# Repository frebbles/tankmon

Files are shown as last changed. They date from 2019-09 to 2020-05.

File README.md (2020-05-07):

# TankMon

A no frills dual tank water level monitoring solution incorporating:

- ESP8266 low power ultrasonic measurer remote monitor and reporter device for dual tank setups [tankmon-probedual] 
Open this in Arduino, ensure that ESP8266 is installed as per the [Adafruit esp8266 arduino guide](https://learn.adafruit.com/adafruit-io-basics-esp8266-arduino/using-arduino-ide)

- PHP server receiver and graph display tool [tankmon]
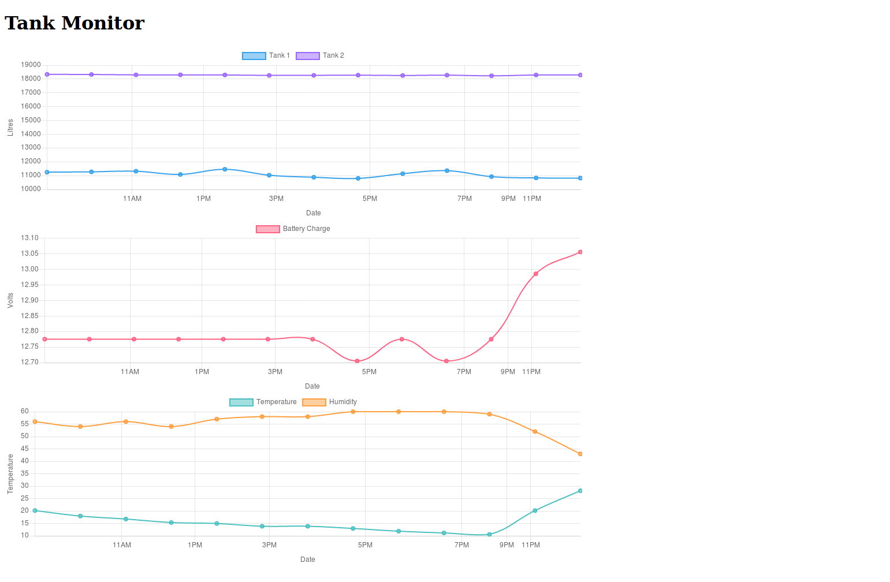
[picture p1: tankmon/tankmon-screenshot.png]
TankMon screenshot


- OpenSCAD construction for Ultrasonic case and ESP8266/NODEMCU case [tankmon-cases]
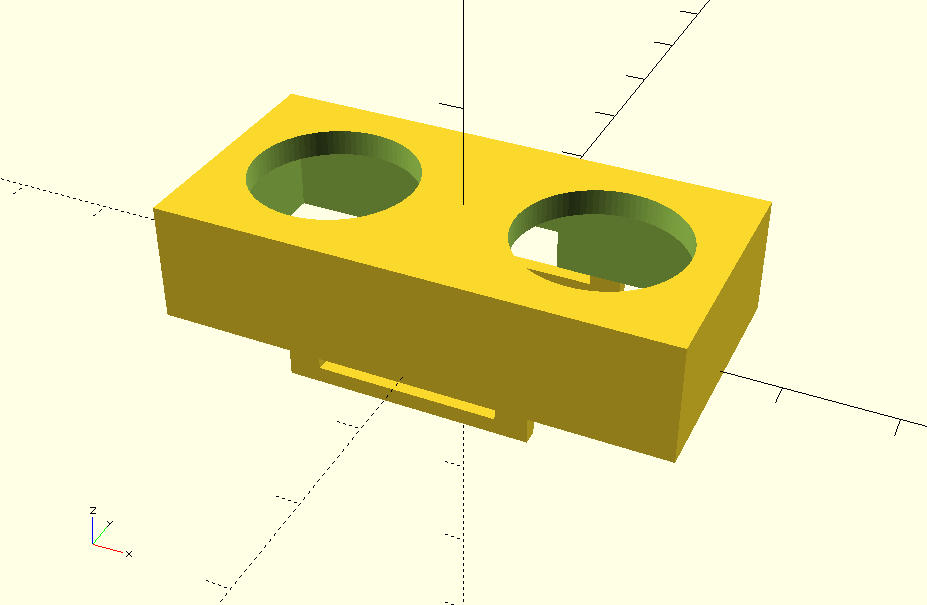
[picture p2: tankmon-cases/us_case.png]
OpenSCAD Ultrasonics case


- Circuit Design and construction for remote monitor circuit and board pcb in KiCAD [tankmon-pcb]
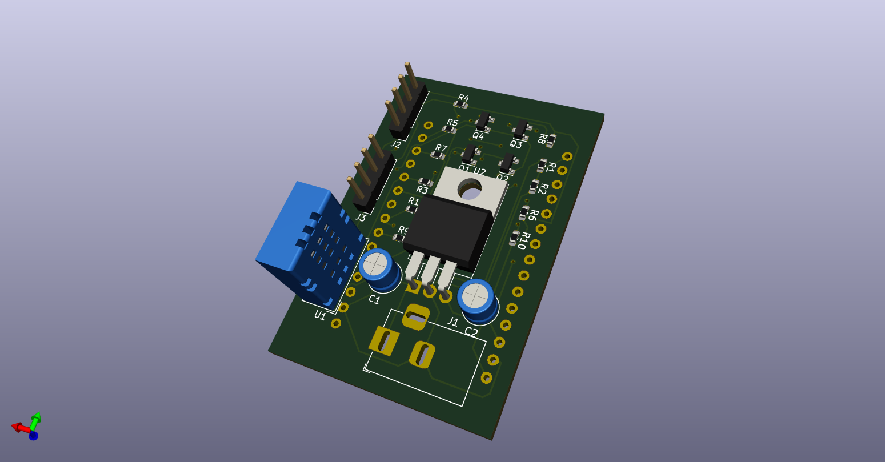
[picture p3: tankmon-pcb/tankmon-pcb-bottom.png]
tankmon-pcb-bottom


A demonstration exercise in, simplifying workflows and modularity, utilising Arduino, NodeMCU, KiCAD, OpenSCAD.

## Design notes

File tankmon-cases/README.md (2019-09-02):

- OpenSCAD case function designs for Make-A-Bracket and Tank fitment for Make-A-Bracket

Function call for make a bracket makes quick development of cases possible, use the following:
use <mab_case_func.scad>

Which simplifies the cases for both the Ultrasonic sensor and the NodeMCU and wiring board.

Work smarter, not harder!

The files us_case and us_case_plug correspond to cases using the above functions for case construction and plug/cap construction.

OpenSCAD Ultrasonics case

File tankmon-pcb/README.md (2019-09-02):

TANKMON NodeMCU PCB adaptor for ultrasonic sensors

These have been designed using KiCAD 5.1.2

Open the project in KiCAD to view/modify the PCB. Export to gerber for sending to your friendly board house for production.

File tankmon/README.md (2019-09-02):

== Tank Monitor Web Scripts

Place these into a /tankmon/ directory of the web server you wish to host this on, the ip/dns of the server must be programmed into the
tankmon-probedual arduino source file for the esp8266 to contact and log the information.

-- Contribs

 - Use of graphing library from ChartJS - minimised and cut down for MVP of graphing required for tank reporting

 - Script for reporting from ESP8266 in remote tank location/s

 - Script for visualisation of past reported tank depth information

 - Tank details stored in CSV file for each individual tank

 - web_test.sh script to start local php service and run browser for testing, (REMOVE before deployment)

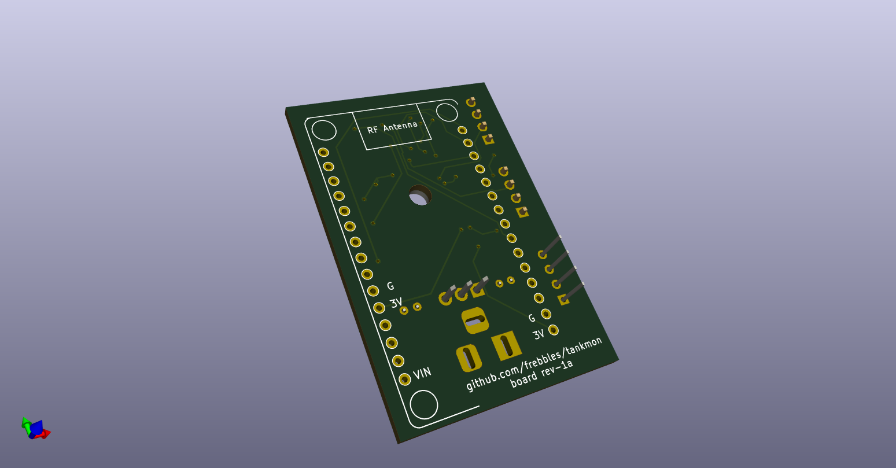
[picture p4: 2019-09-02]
tankmon-pcb/tankmon-pcb-top.png

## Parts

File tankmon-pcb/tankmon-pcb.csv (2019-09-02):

Id | Designator | Package | Quantity | Designation | Supplier and ref
1 | U3 | ESP12F-Devkit-V3-modtext | 1 | NodeMCU_1.0_(ESP-12E)
2 | U2 | TO-220-3_Horizontal_TabDown | 1 | L7805
3 | U1 | Aosong_DHT11_5.5x12.0_P2.54mm | 1 | DHT11
4 | R11,R10,R9,R8,R7,R6,R5,R4 | R_0603_1608Metric | 8 | 10K
5 | R3,R2 | R_0603_1608Metric | 2 | 10k
6 | R1 | R_0603_1608Metric | 1 | 220k
7 | Q4,Q3,Q2,Q1 | SOT-23 | 4 | BSS138
8 | J3,J2 | PinHeader_1x04_P2.54mm_Vertical | 2 | Conn_01x04_Male
9 | J1 | BarrelJack_Horizontal | 1 | Barrel_Jack
10 | C2 | C_Radial_D5.0mm_H5.0mm_P2.00mm | 1 | 0.1uF
11 | C1 | C_Radial_D5.0mm_H5.0mm_P2.00mm | 1 | 0.33uF

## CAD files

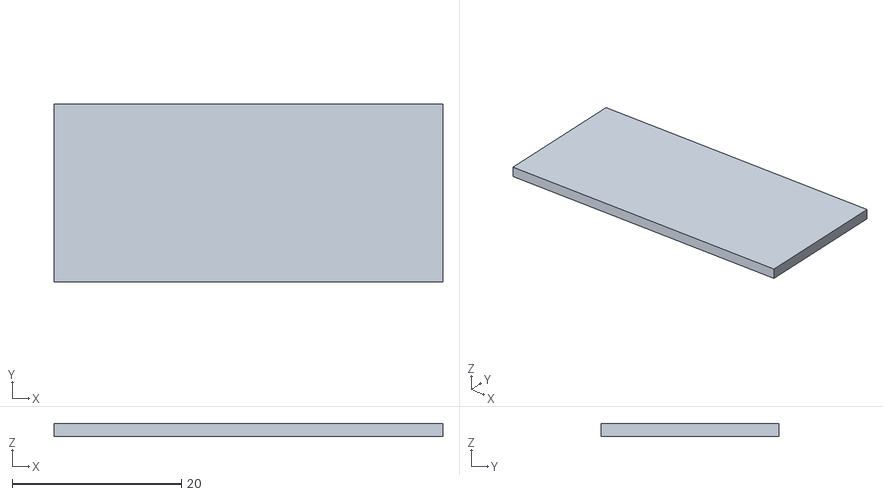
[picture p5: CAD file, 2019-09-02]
tankmon-cases/us_case_plug.stl
46.0 x 21.0 x 1.50

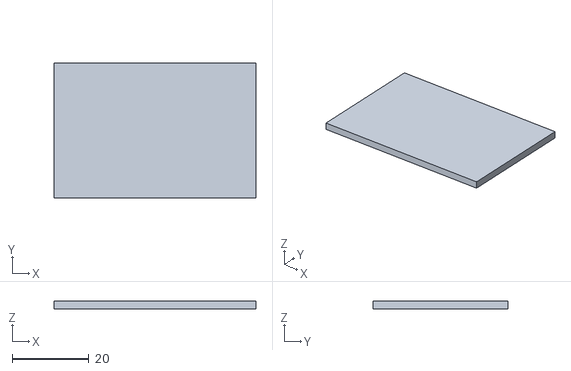
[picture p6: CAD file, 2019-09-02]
tankmon-cases/nodemcu_case_plug_tubemount.stl
52.5 x 35.0 x 2.00

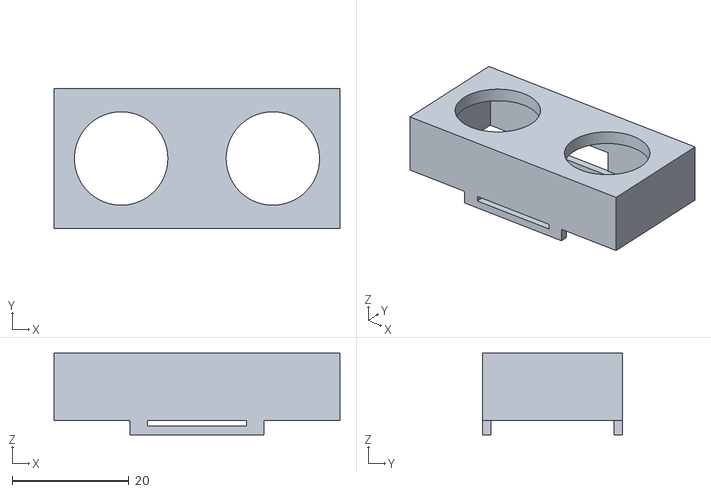
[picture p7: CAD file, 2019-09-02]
tankmon-cases/us_case.stl
49.0 x 24.0 x 14.0

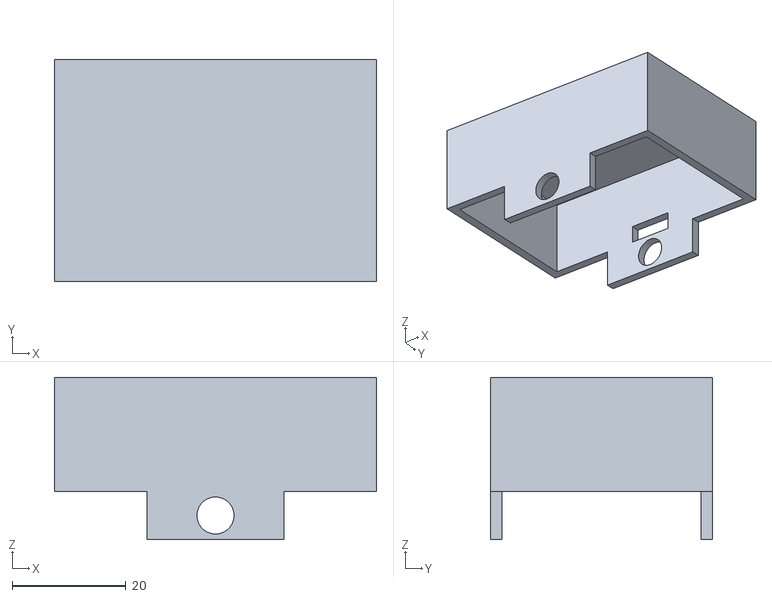
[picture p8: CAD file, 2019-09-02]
tankmon-cases/nodemcu_case_tubemount.stl
56.5 x 39.0 x 28.5

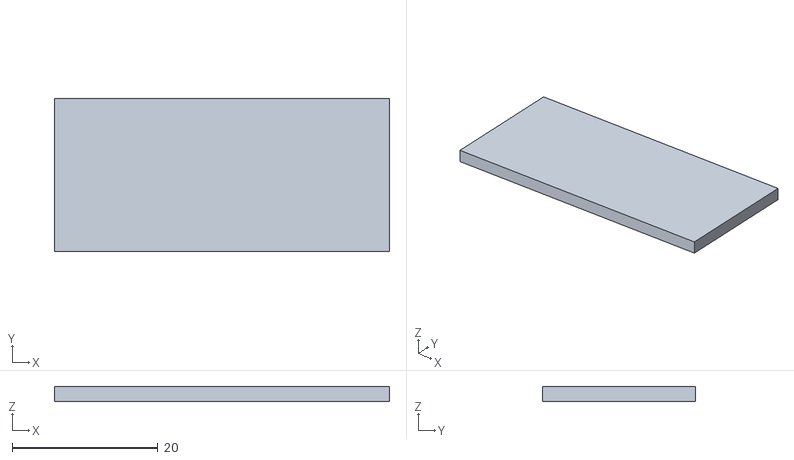
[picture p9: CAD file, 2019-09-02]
tankmon-cases/us_case_plug_tubemount.stl
46.0 x 21.0 x 2.00

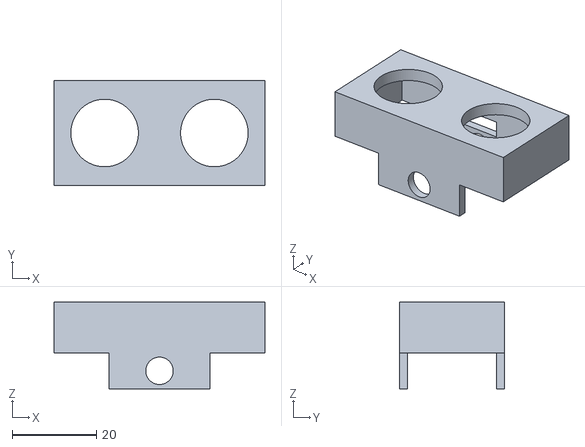
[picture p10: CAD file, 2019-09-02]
tankmon-cases/us_case_tubemount.stl
50.0 x 25.0 x 20.5

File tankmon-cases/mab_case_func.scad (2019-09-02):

echo(version=version());

transblue = [0.5,0.5,0.9,0.8];

mabWidth = 20;
mabThick = 2.5;

// Create case for "Make a bracket" from bunnings warehouse
//mab_rail_case(56, 20, 8.5, 2);
// Create plug for above case
//mab_rail_case_plug(56,20,2);

module mab_rail_case_plug(intwidth, intlength, thickness)
// Subsection plug for case
color("green") 
    translate([0,0,-1])
    linear_extrude(height=thickness)
        square([intwidth,intlength], center= true);


module mab_rail_case(intwidth, intlength, intheight, thickness) {
// Case primary
    
outerlength = intlength + (thickness*2);
outerwidth = intwidth + (thickness*2);
outerheight = intheight + (thickness*2);

union() {

difference() {
union() {
translate([0,(intlength+thickness)/2,-(thickness+1+mabThick)])
linear_extrude(height=thickness + mabThick)
square(size=[(mabWidth + (thickness*2)),thickness], center=true);

translate([0,-(intlength+thickness)/2,-(thickness+1+mabThick)])
linear_extrude(height=thickness + mabThick)
square(size=[(mabWidth + (thickness*2)),thickness], center=true);
}


// For a square sectional mount
translate([0,0,-mabThick-1])
linear_extrude(height=mabThick)
square(size=[mabWidth,intlength*2], center=true);
}


// Main section
difference() {
color(transblue)
    translate([0,0,-1])
        linear_extrude(height=intheight+thickness)
            square([outerwidth, outerlength], center=true);
color("red") 
    translate([0,0,-2])
    linear_extrude(height=intheight)
        square([intwidth,intlength], center= true);
        
color("black")
    translate([0,outerlength/2-thickness/2,-1])
    linear_extrude(height=4)
        square([10,3], center=true);
}
}

}

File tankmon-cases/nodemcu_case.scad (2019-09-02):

use <shaft_mount_func.scad>

cyl_rail_case(52.5,35,18,2);

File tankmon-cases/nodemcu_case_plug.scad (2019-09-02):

use <shaft_mount_func.scad>

cyl_rail_case_plug(52.5,35,2);

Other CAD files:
tankmon-cases/shaft_mount_func.scad
tankmon-cases/us_case.scad
tankmon-cases/us_case_plug.scad

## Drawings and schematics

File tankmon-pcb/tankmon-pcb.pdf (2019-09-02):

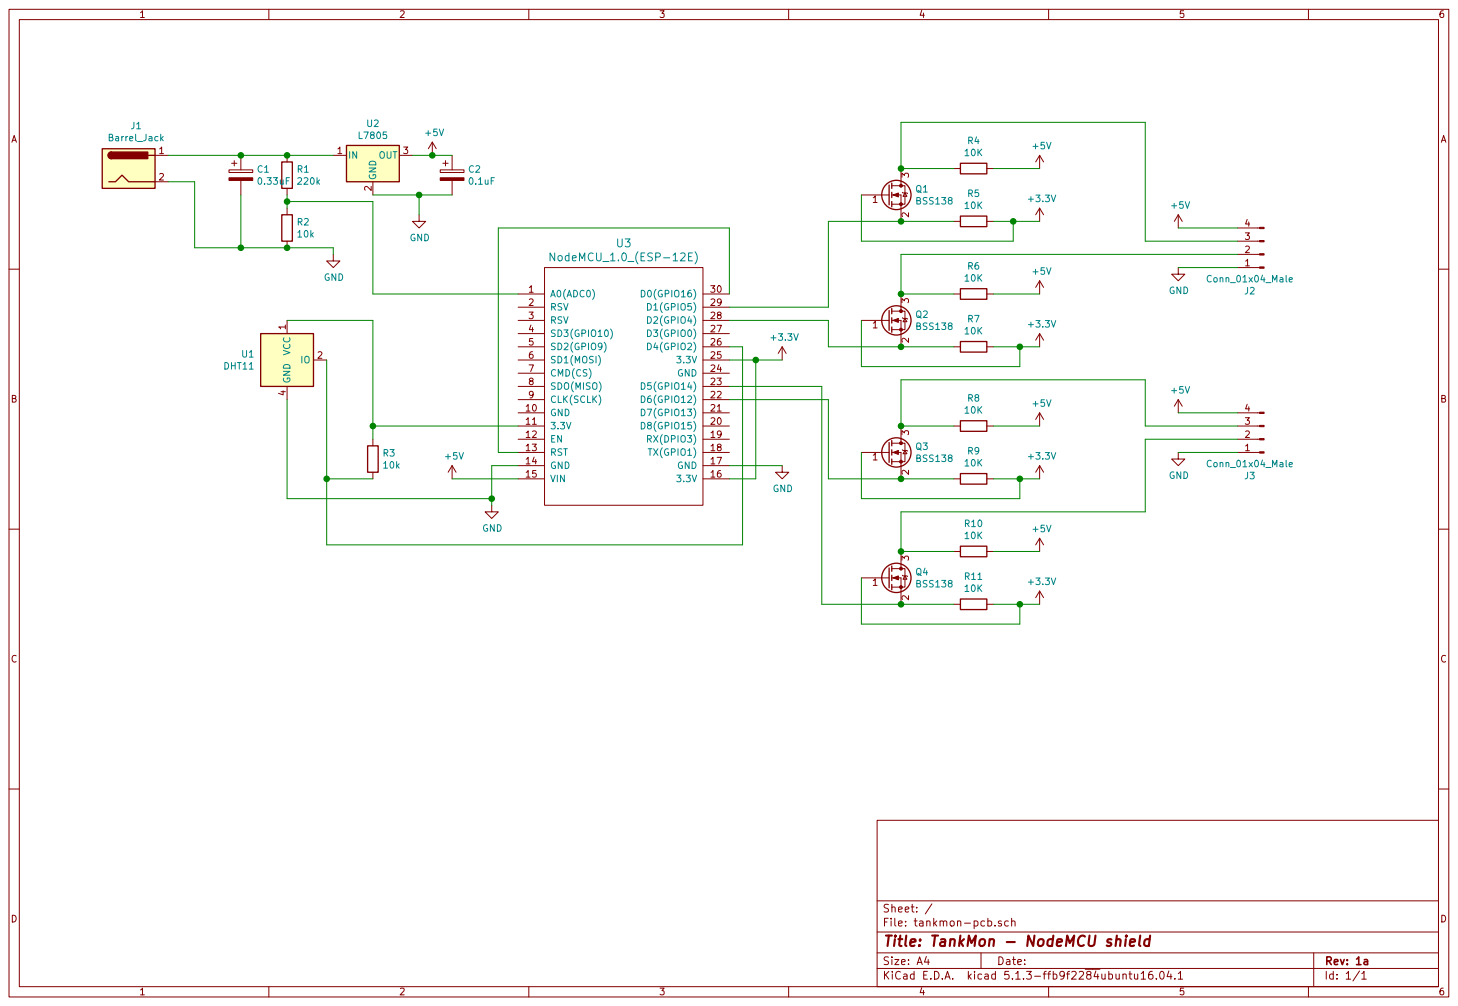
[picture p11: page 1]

File: tankmon-pcb.sch Sheet: /
Id: 1/1 Title: TankMon - NodeMCU shield

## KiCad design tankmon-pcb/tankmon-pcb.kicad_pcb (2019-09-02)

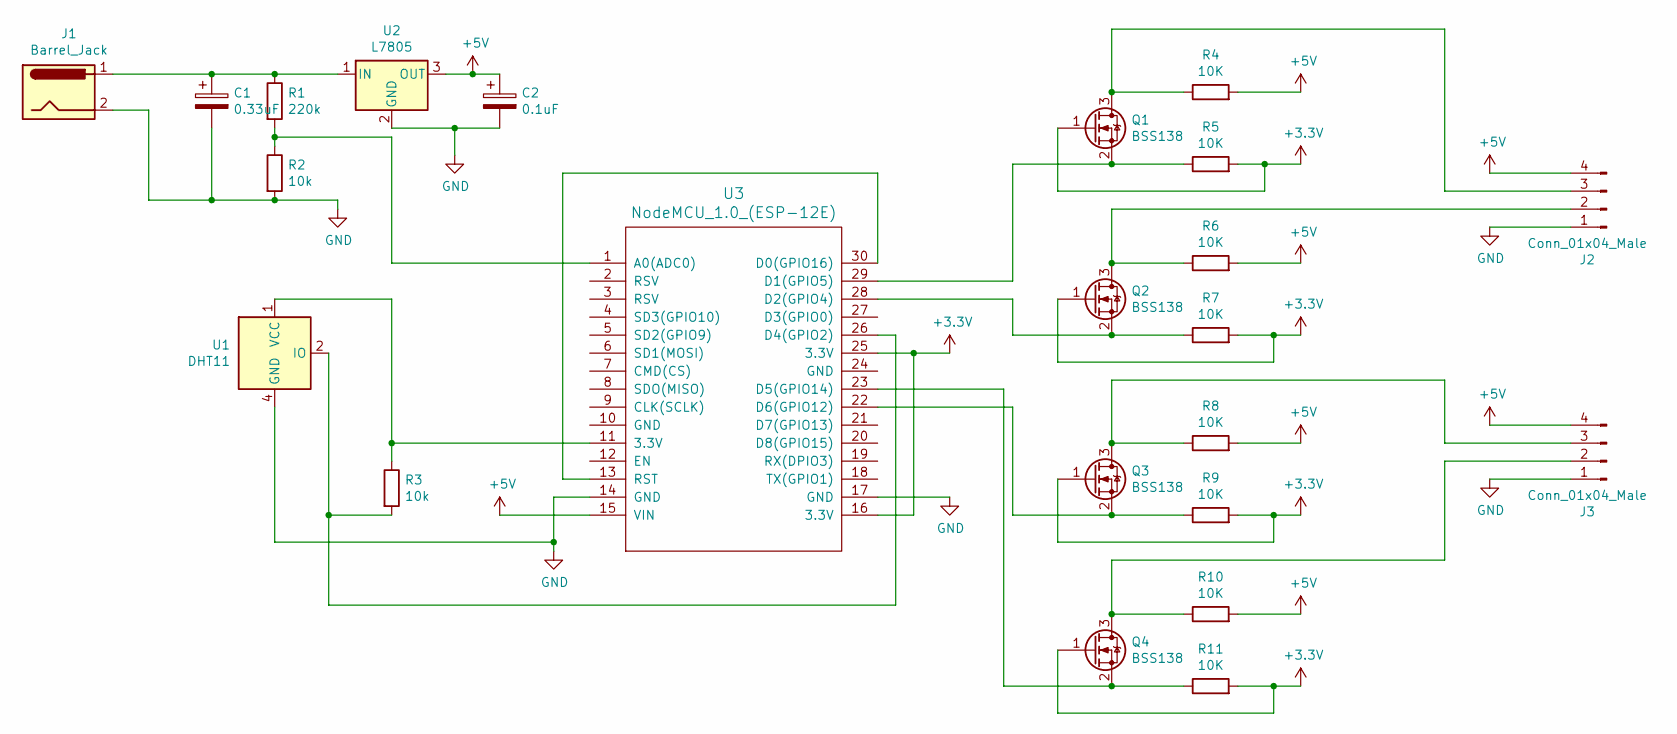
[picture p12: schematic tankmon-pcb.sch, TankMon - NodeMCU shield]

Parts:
C1: 0.33uF; C_Radial_D5.0mm_H5.0mm_P2.00mm
C2: 0.1uF; C_Radial_D5.0mm_H5.0mm_P2.00mm
J1: Barrel_Jack; BarrelJack_Horizontal
J2, J3: Conn_01x04_Male; PinHeader_1x04_P2.54mm_Vertical
Q1, Q2, Q3, Q4: BSS138; SOT-23
R1: 220k; R_0603_1608Metric
R2, R3: 10k; R_0603_1608Metric
R4, R5, R6, R7, R8, R9, R10, R11: 10K; R_0603_1608Metric
U1: DHT11; Aosong_DHT11_5.5x12.0_P2.54mm
U2: L7805; TO-220-3_Horizontal_TabDown
U3: NodeMCU_1.0_(ESP-12E); ESP12F-Devkit-V3

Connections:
+3V3: Q1.1 (G), Q2.1 (G), Q3.1 (G), Q4.1 (G), R5.2, R7.2, R9.2, R11.2, U3.16 (3.3V), U3.25 (3.3V)
+5V: C2.1, J2.4, J3.4, R4.2, R6.2, R8.2, R10.2, U2.3 (OUT), U3.15 (VIN)
GND: C1.2, C2.2, J1.2, J2.1, J3.1, R2.2, U1.4 (GND), U2.2 (GND), U3.14 (GND), U3.17 (GND)
unnamed: C1.1, J1.1, R1.1, U2.1 (IN)
unnamed: J2.2, Q2.3 (D), R6.1
unnamed: J2.3, Q1.3 (D), R4.1
unnamed: J3.2, Q4.3 (D), R10.1
unnamed: J3.3, Q3.3 (D), R8.1
unnamed: Q1.2 (S), R5.1, U3.29 (D1(GPIO5))
unnamed: Q2.2 (S), R7.1, U3.28 (D2(GPIO4))
unnamed: Q3.2 (S), R9.1, U3.22 (D6(GPIO12))
unnamed: Q4.2 (S), R11.1, U3.23 (D5(GPIO14))
unnamed: R1.2, R2.1, U3.1 (A0(ADC0))
unnamed: R3.1, U1.1 (VCC), U3.11 (3.3V)
unnamed: R3.2, U1.2 (IO), U3.26 (D4(GPIO2))
unnamed: U3.13 (RST), U3.30 (D0(GPIO16))

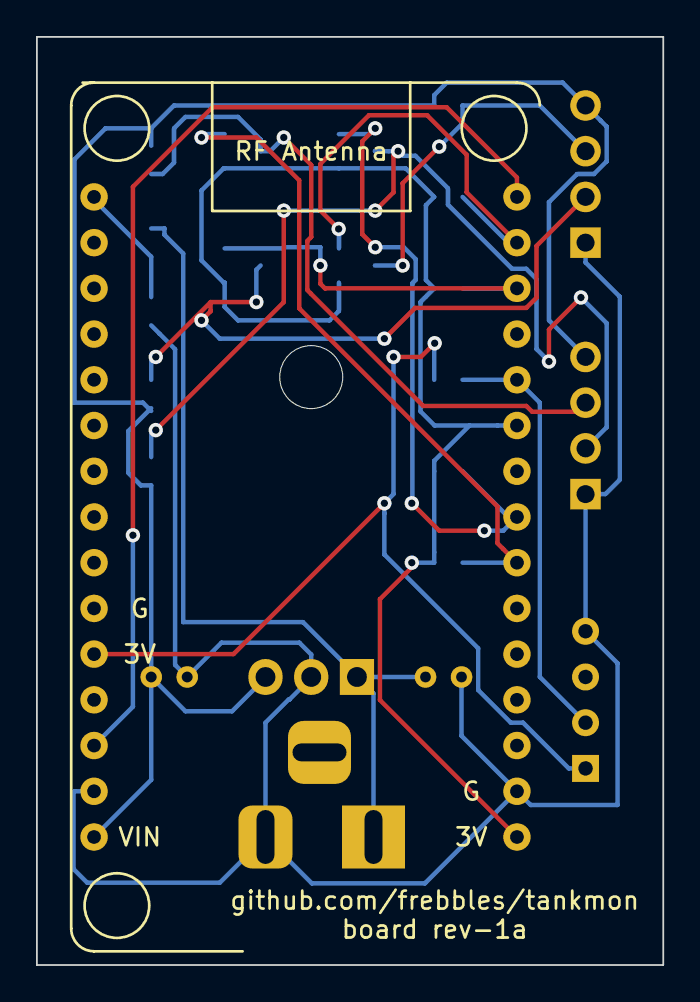
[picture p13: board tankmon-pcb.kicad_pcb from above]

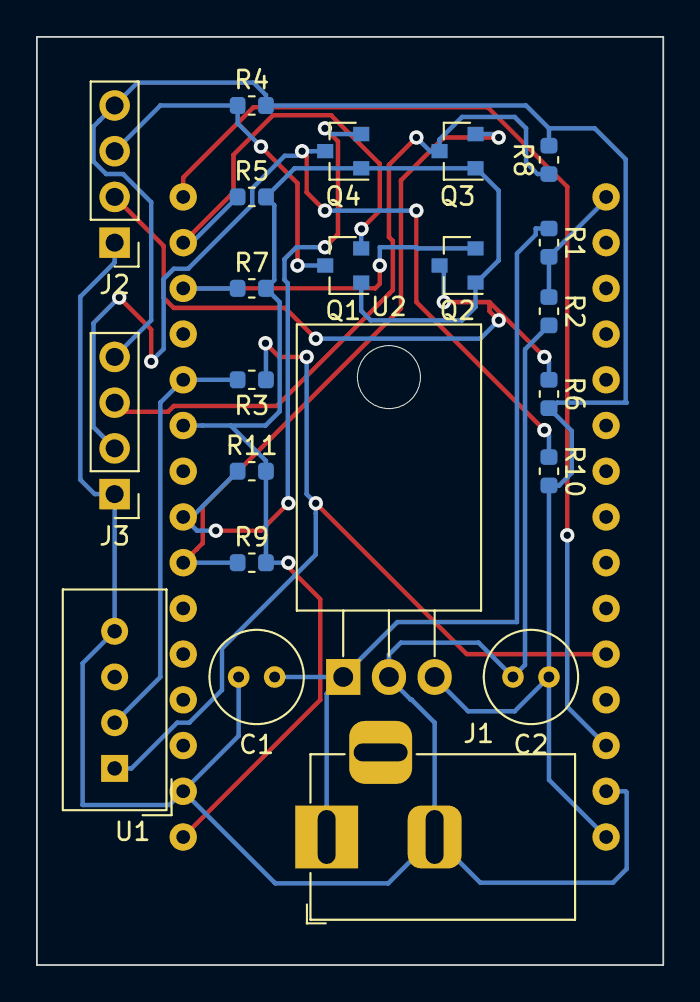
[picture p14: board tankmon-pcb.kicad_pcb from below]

Board: 2 copper layers, 34.8 x 51.6 mm, 23 parts (22 on the bottom side), 16 nets.

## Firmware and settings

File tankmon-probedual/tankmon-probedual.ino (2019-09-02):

/* 
 *  Dual Tank monitor and HTTP Reporter
 *  
 *  Author: F.Rebbeck
 *  github.com/frebbles/tankmon
 */

#include <Arduino.h>
#include <ESP8266WiFi.h>
#include <ESP8266WiFiMulti.h>
#include <ESP8266HTTPClient.h>
#include <WiFiClient.h>
#include "DHT.h"

// CONFIGURATION
#define SLEEP_PERIOD 3600e6
#define AP_NAME "AP_NAME_HERE"
#define AP_PSK "AP_PASSOWRD_HERE"
#define SERVER_IP "192.168.1.1"
#define DHTPIN 2        //D4     // Digital pin connected to the DHT sensor
#define DHTTYPE DHT11   // DHT 11

// Initialize DHT sensor.
DHT dht(DHTPIN, DHTTYPE);

// Use the quick WiFiMulti library for connection
ESP8266WiFiMulti WiFiMulti;

// Define pins numbers for ultrasonic sensors attached
const int trig1Pin = 5; //D1
const int echo1Pin = 4; //D2
const int trig2Pin = 12;//D6
const int echo2Pin = 14;//D5

// Allowable attempts to upload data before just going back to sleep (save battery life)
int connAttempts = 10;

// Make multiple samples and average result before returning.
float sampleAvg(int trigPin, int echoPin, int count) {
  float average = 0;
  float distance = 0;
  long duration = 0;
  int validreads = 0;

  // Waste a few samples to let US sensors settle
  for (int w = 0; w < 5; w++) {
    // Clears the trigPin
    digitalWrite(trigPin, LOW);
    delayMicroseconds(2);

    // Sets the trigPin on HIGH state for 10 micro seconds
    digitalWrite(trigPin, HIGH);
    delayMicroseconds(10);
    digitalWrite(trigPin, LOW);
    duration = pulseIn(echoPin, HIGH, 1000000);
  }
  
  Serial.print("Begin sampling...");
  for (int i = 0; i < count; i++) {
    // Clears the trigPin
    digitalWrite(trigPin, LOW);
    delayMicroseconds(2);

    // Sets the trigPin on HIGH state for 10 micro seconds
    digitalWrite(trigPin, HIGH);
    delayMicroseconds(10);
    digitalWrite(trigPin, LOW);
  
    duration = pulseIn(echoPin, HIGH, 1000000);
    if (duration > 0) validreads++;
    distance = duration*(0.034/2); //(duration / 29.0) / 2.0;
    average += distance;
    Serial.print(" reading: ");
    Serial.print(distance);
  }
  Serial.println("done.");
  if (validreads > 0) {
  return (average / validreads);
  } else {
  return 0;
  }
}


void setup() {
  pinMode(trig1Pin, OUTPUT); // Sets the trigPin1 as an Output
  pinMode(echo1Pin, INPUT);  // Sets the echoPin1 as an Input
  pinMode(trig2Pin, OUTPUT); // Sets the trigPin2 as an Output
  pinMode(echo2Pin, INPUT);  // Sets the echoPi2n as an Input
  delayMicroseconds(200);    // Settle time.
  Serial.begin(115200);      // Starts the serial communication
  Serial.println("\nStartup...");  
  delayMicroseconds(20000);
}

void loop() {
  float distance1;
  float distance2;

  // Sample data for snapshot
  distance1 = sampleAvg(trig1Pin, echo1Pin, 3);// * 0.034/2;
  distance2 = sampleAvg(trig2Pin, echo2Pin, 3);// * 0.034/2;
  
  // Prints the distance on the Serial Monitor
  Serial.print("Distances: ");
  Serial.printf("1==%f cm    2==%f cm\n", distance1, distance2);

  // Reading temperature or humidity takes about 250 milliseconds!
  dht.begin();
  // Sensor readings may also be up to 2 seconds 'old' (its a very slow sensor)
  float h = dht.readHumidity();
  // Read temperature as Celsius (the default)
  float t = dht.readTemperature();
  Serial.print(F("Humidity: "));
  Serial.print(h);
  Serial.print(F("%  Temperature: "));
  Serial.print(t);
  Serial.print(F("°C "));

  // Read system/battery voltage
  int aVal = analogRead(A0);
  Serial.print("Analog read: ");
  Serial.println(aVal);
  float vVal = 0;
  
  vVal = ((aVal*17.9)/255.0);

  WiFi.mode(WIFI_STA);       // Set as Station
  WiFiMulti.addAP(AP_NAME,AP_PSK); // Wifi credentials here.
  delayMicroseconds(1000000); // Wifi settle
  
  // Connect to AP 
  Serial.println("Connect to WiFi...");
  if ((WiFiMulti.run() == WL_CONNECTED)) {
    WiFiClient client;
    HTTPClient http;
     Serial.println("HTTP Start");
     char rstr[128];
     char d1str[16];
     char d2str[16];
     char hstr[16];
     char tstr[16];
     char vstr[16];
     strcpy(rstr, "http://");
     strcat(rstr, SERVER_IP);
     strcat(rstr, "/tankmon/clientReport.php?d1=");
     sprintf(d1str, "%f", distance1);
     sprintf(d2str, "%f", distance2);
     strcat(rstr, d1str);
     strcat(rstr, "&d2=");
     strcat(rstr, d2str);
     sprintf(hstr, "%f", h);
     sprintf(tstr, "%f", t);
     strcat(rstr, "&h=");
     strcat(rstr, hstr);
     strcat(rstr, "&t=");
     strcat(rstr, tstr);
     strcat(rstr, "&v=");
     sprintf(vstr, "%f", vVal);
     strcat(rstr, vstr);
     
     Serial.printf("HTTP REQ: %s\n",rstr);
     
     if (http.begin(client, rstr)) {
       Serial.print("HTTP Get \n");
       int httpCode = http.GET();
       if (httpCode > 0) {
         Serial.printf("HTTP Code %d \n", httpCode);
       } else {
         Serial.printf("HTTP failed error %s\n", http.errorToString(httpCode).c_str());
       }
       http.end();
       delay(1000);
       Serial.printf("Going to sleep....\n");
       ESP.deepSleep(SLEEP_PERIOD);
     } else {
      Serial.printf("HTTP Unable to connect\n");
     }
  }
  delay(5000);

  connAttempts--;
  if (connAttempts < 1) {
    // Sleep for an hour
    Serial.printf("Connection attempts failed, sleeping\n");
    ESP.deepSleep(SLEEP_PERIOD);
  }
}
